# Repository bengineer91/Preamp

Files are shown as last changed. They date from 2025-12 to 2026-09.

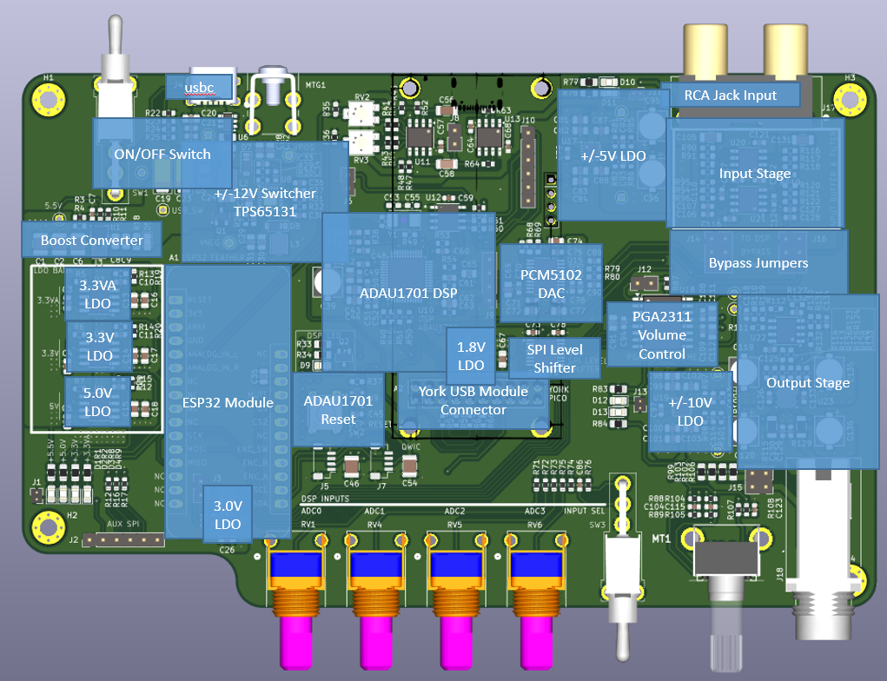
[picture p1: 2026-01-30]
layout/component_locations.PNG

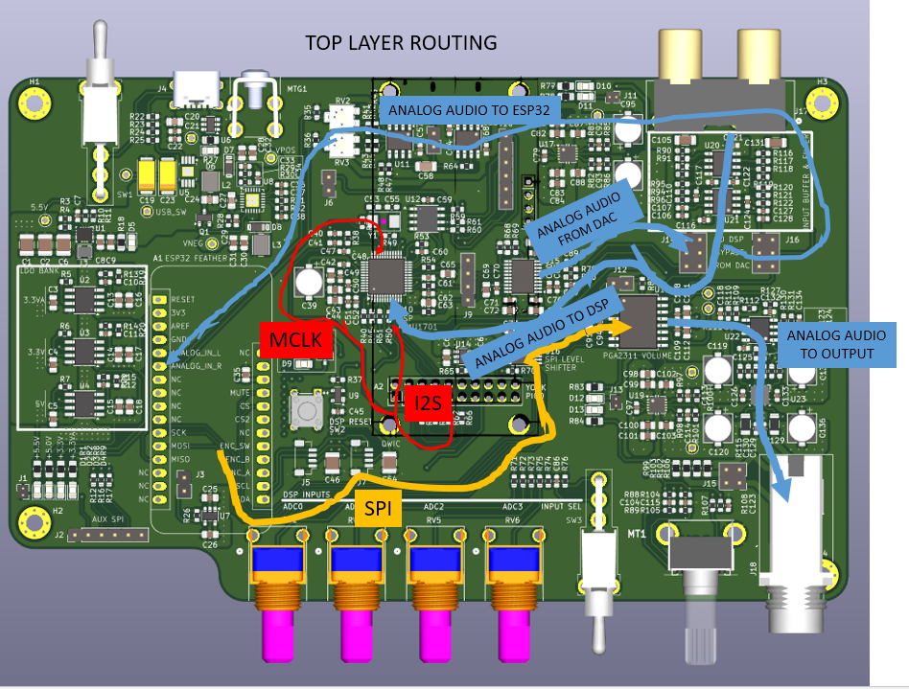
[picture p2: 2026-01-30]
layout/routing_overview.PNG

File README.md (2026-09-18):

# Preamp
** Note ** This got to the ready-to-buy-boards stage when I archived it for more interesting things.

Headphone amplifier with the following features:

- USBC Power Input
- 5V, 3.3V, 3.3VA, and 1.8V LDOs
- +/-12V split rail switching converter, feeding +/-10V and +/-5V LDOs
- ESP32 Module for control and driving a spectrum visualizer OLED display
- York Pico USB to I2S module
- ADAU1701 DSP
- PCM5102A Digital to Analog Converter
- PGA2311 digital volume controller

block_diagram
Capture

**To Do:** <br/>
[x] Update Block Diagram with power architecture changes<br/>

Layout:<br/>
[x] Verify component placement<br/>
[x] Routing!<br/>

Schematic:<br/>
[x] Clean up placement<br/>
[x] Part selection for capacitors, verify voltages on schematic<br/>
[x] Reduce footprint sizes where possible, mainly capacitors<br/>
[x] Pick proper connectors for the front panel stuff<br/>
[ ] Decide on header stack height for the York and ESP32<br/>

ESP32 Code<br/>
[x] Port over spectrum visualizer<br/>
[ ] PGA control<br/>

CAD<br/>
[x] Import board step file<br/>
[x] Figure out rear mounting<br/>
[ ] Layout front/rear panels <br/>

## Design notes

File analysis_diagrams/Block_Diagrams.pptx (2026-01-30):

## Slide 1

Power Converter Chain

USB-C Connector

USB Switch

5V -> 5.5V Boost Converter

5V -> +/-12V Conv

+/-10V LDO

+/-5V LDO

Toggle Switch

3.3VA LDO

3.3VDD LDO

1.8VDD LDO

5VDD LDO

3.0V LDO

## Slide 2

1x toggle switch

Bypass

Toggle Switch

RCA Jack Input

4x rotary potentiometers

PCM5102A DAC

OPAxxxx
Input buffer and DC block

OPAxxxx
Bessel Low Pass Filter

ADAU1701 DSP

PGA2311 Volume Control

Output Stage

I2C, I2S

York Audio Module

EEPROM

Headphone Jack

OLED Display

ESP32
ADC

OPAxxxx
Unity Gain Non Inverting Input Buffer

I2C

SPI

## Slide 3

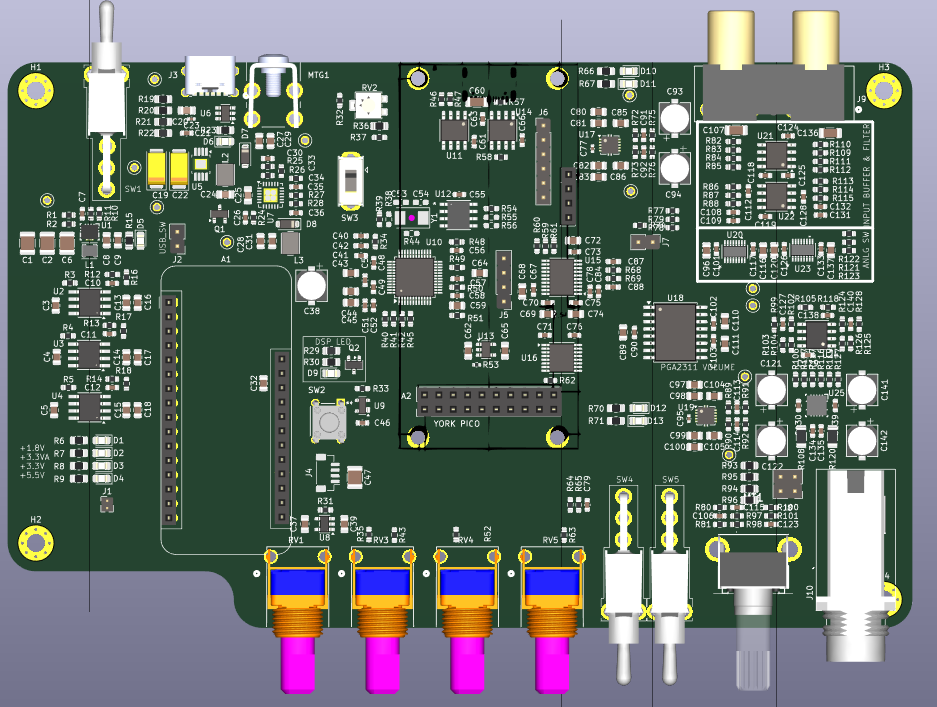
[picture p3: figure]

usbc

+/-5V LDO

RCA Jack Input

Input Stage

Analog Switches

Output Stage

ON/OFF Switch

+/-12V Switcher
TPS65131

ESP32 Module

Boost Converter

ADAU1701 DSP

York USB Module Connector

5.0V LDO

PCM5102 DAC

SPI Level Shifter

3.3VA LDO

1.8V LDO

PGA2311 Volume Control

+/-10V LDO

3.3V LDO

ADAU1701 Reset

3.0V LDO

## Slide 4

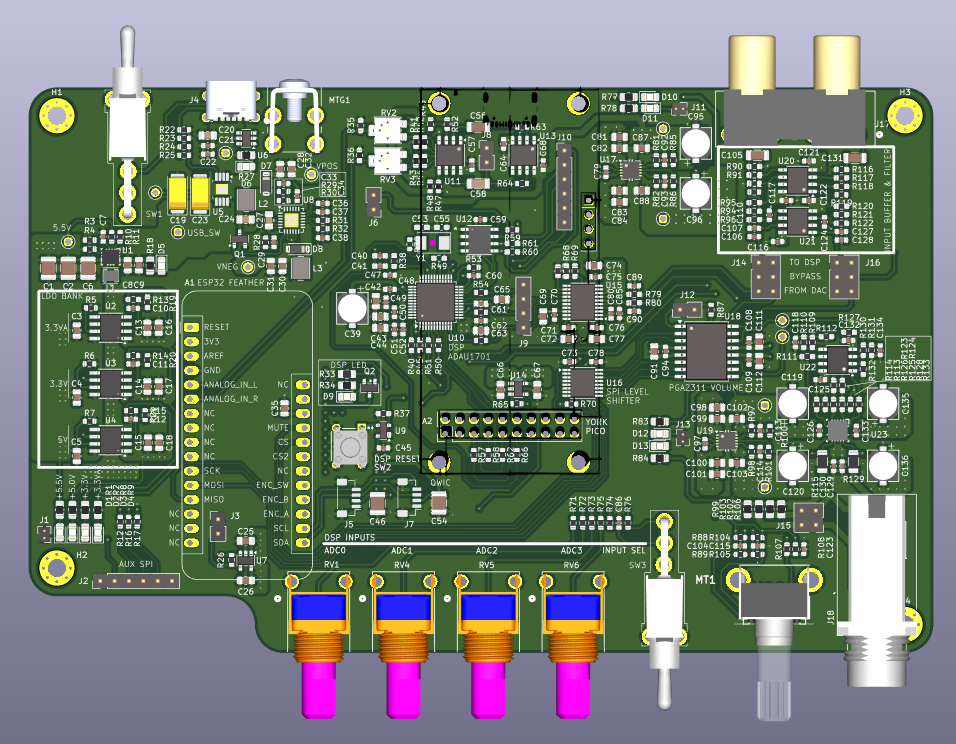
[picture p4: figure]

usbc

+/-5V LDO

RCA Jack Input

Input Stage

Bypass Jumpers

Output Stage

ON/OFF Switch

+/-12V Switcher
TPS65131

ESP32 Module

Boost Converter

ADAU1701 DSP

York USB Module Connector

3.3VA LDO

PCM5102 DAC

SPI Level Shifter

3.3V LDO

1.8V LDO

PGA2311 Volume Control

+/-10V LDO

5.0V LDO

ADAU1701 Reset

3.0V LDO

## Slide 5

TOP LAYER ROUTING

ANALOG AUDIO TO ESP32

ANALOG AUDIO
FROM DAC

ANALOG AUDIO TO DSP

MCLK

I2S

ANALOG AUDIO
TO OUTPUT

SPI

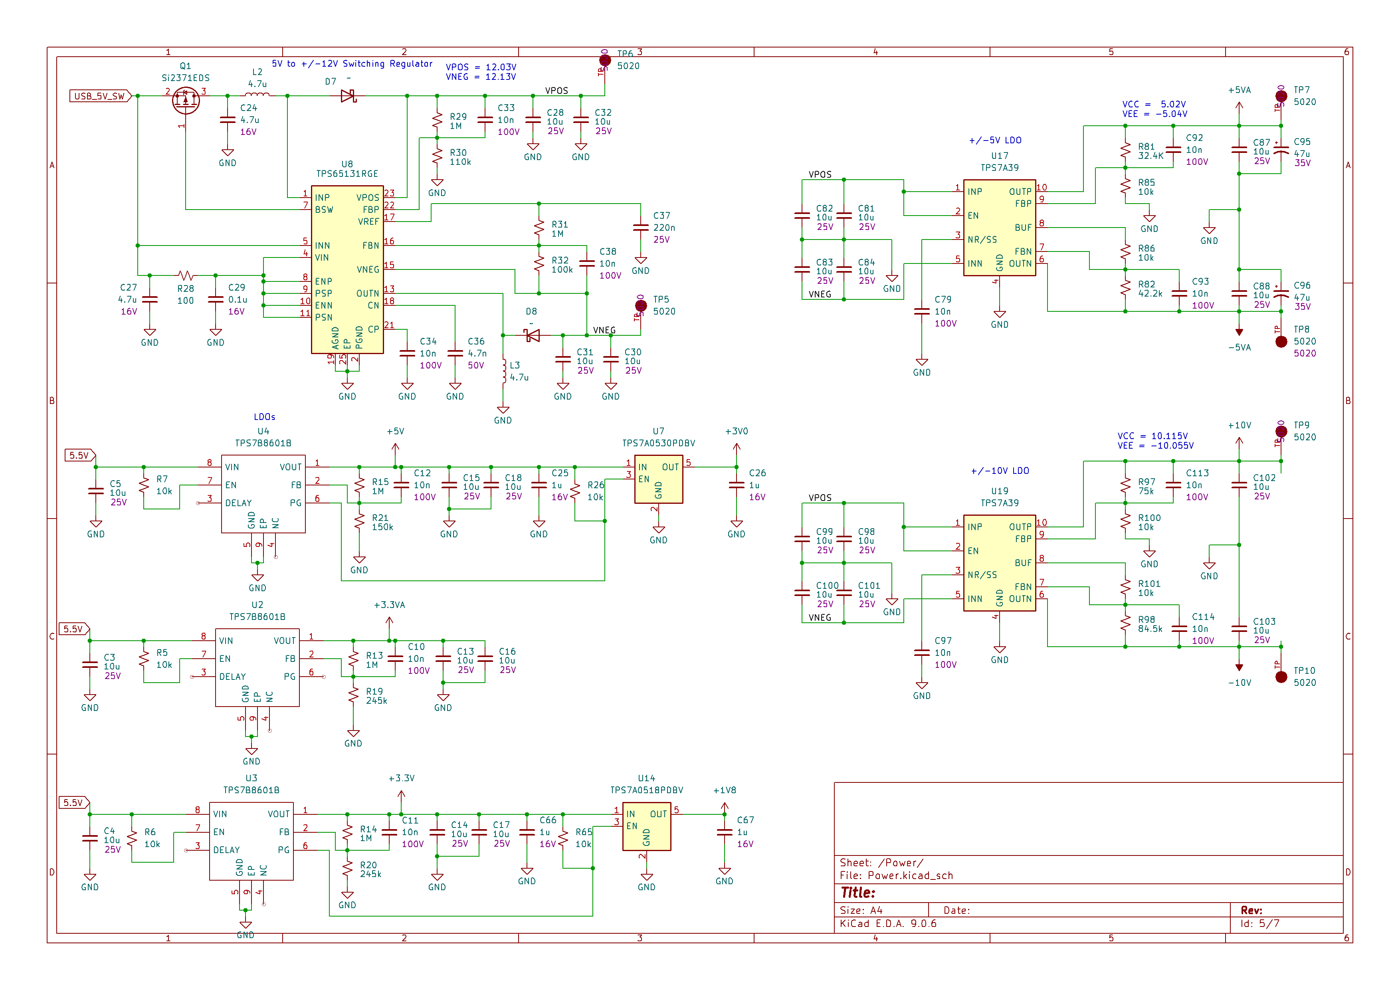
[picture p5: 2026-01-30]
schematic/sheet5.png

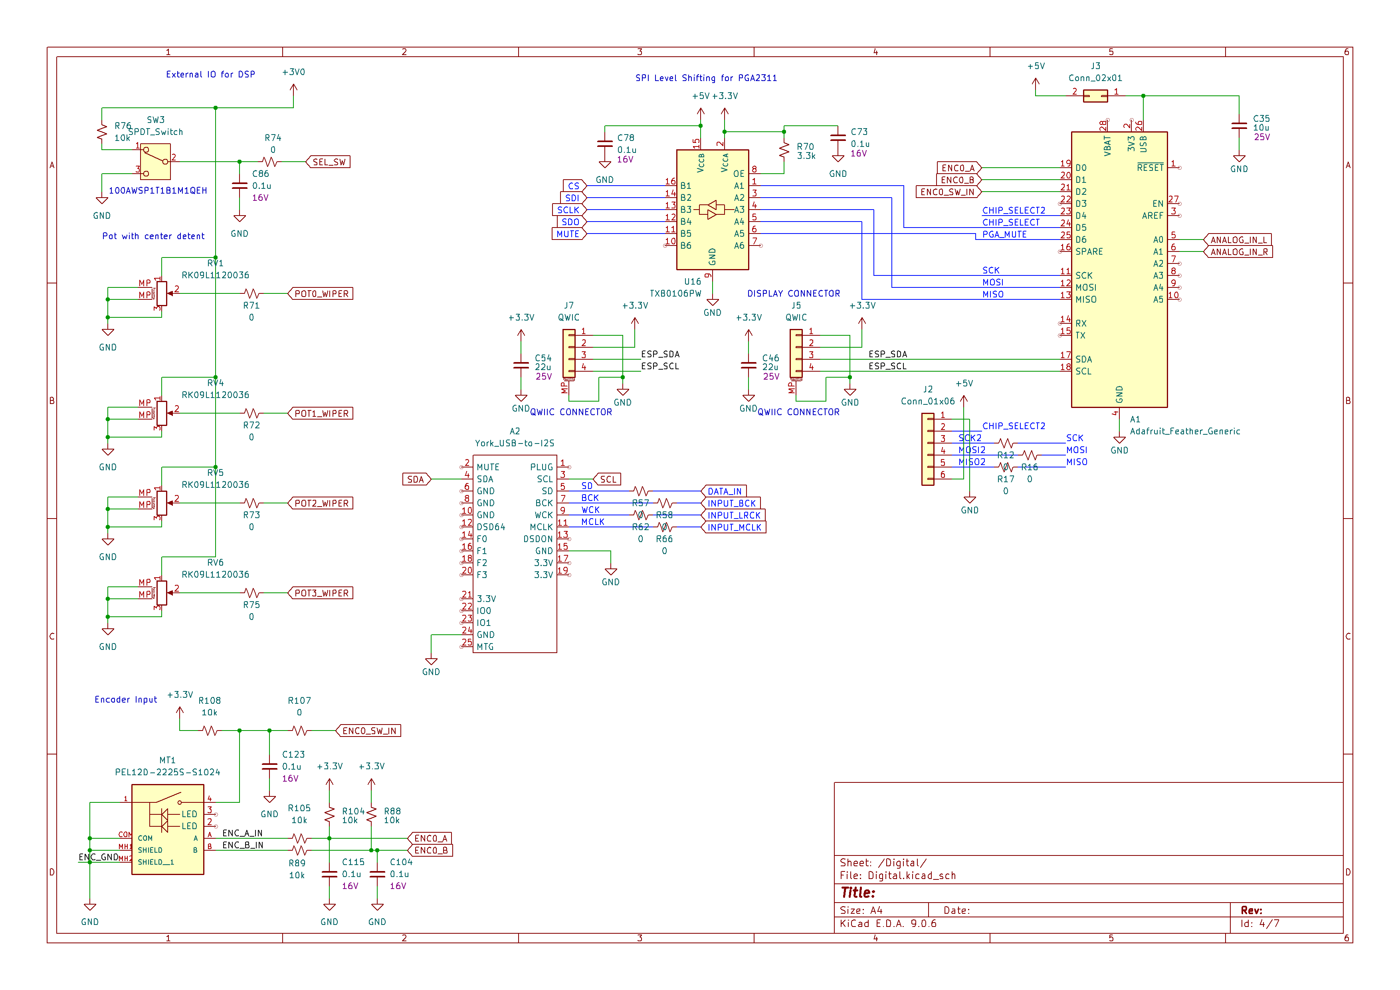
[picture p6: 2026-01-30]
schematic/sheet4.png

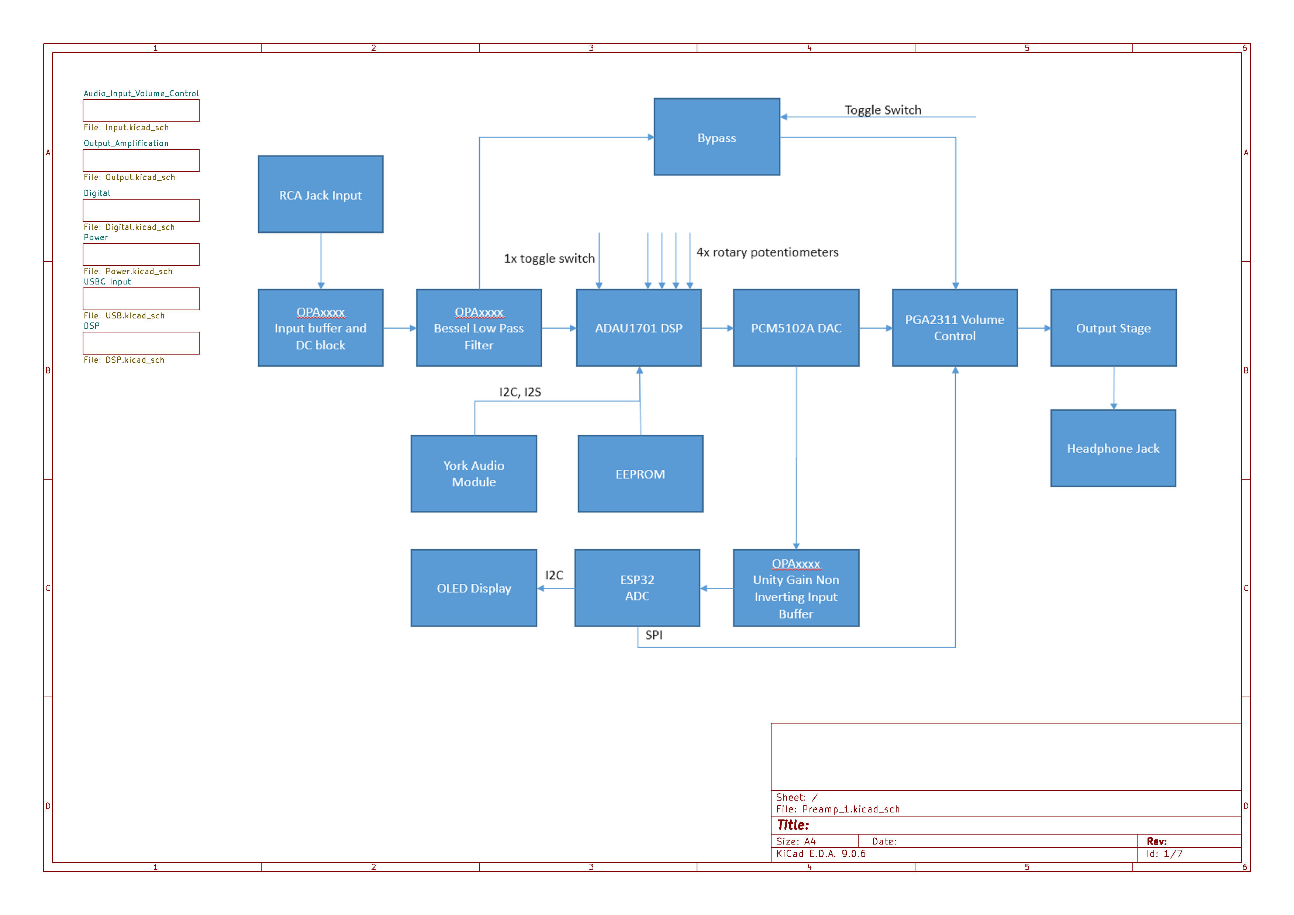
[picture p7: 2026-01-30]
schematic/sheet1.png

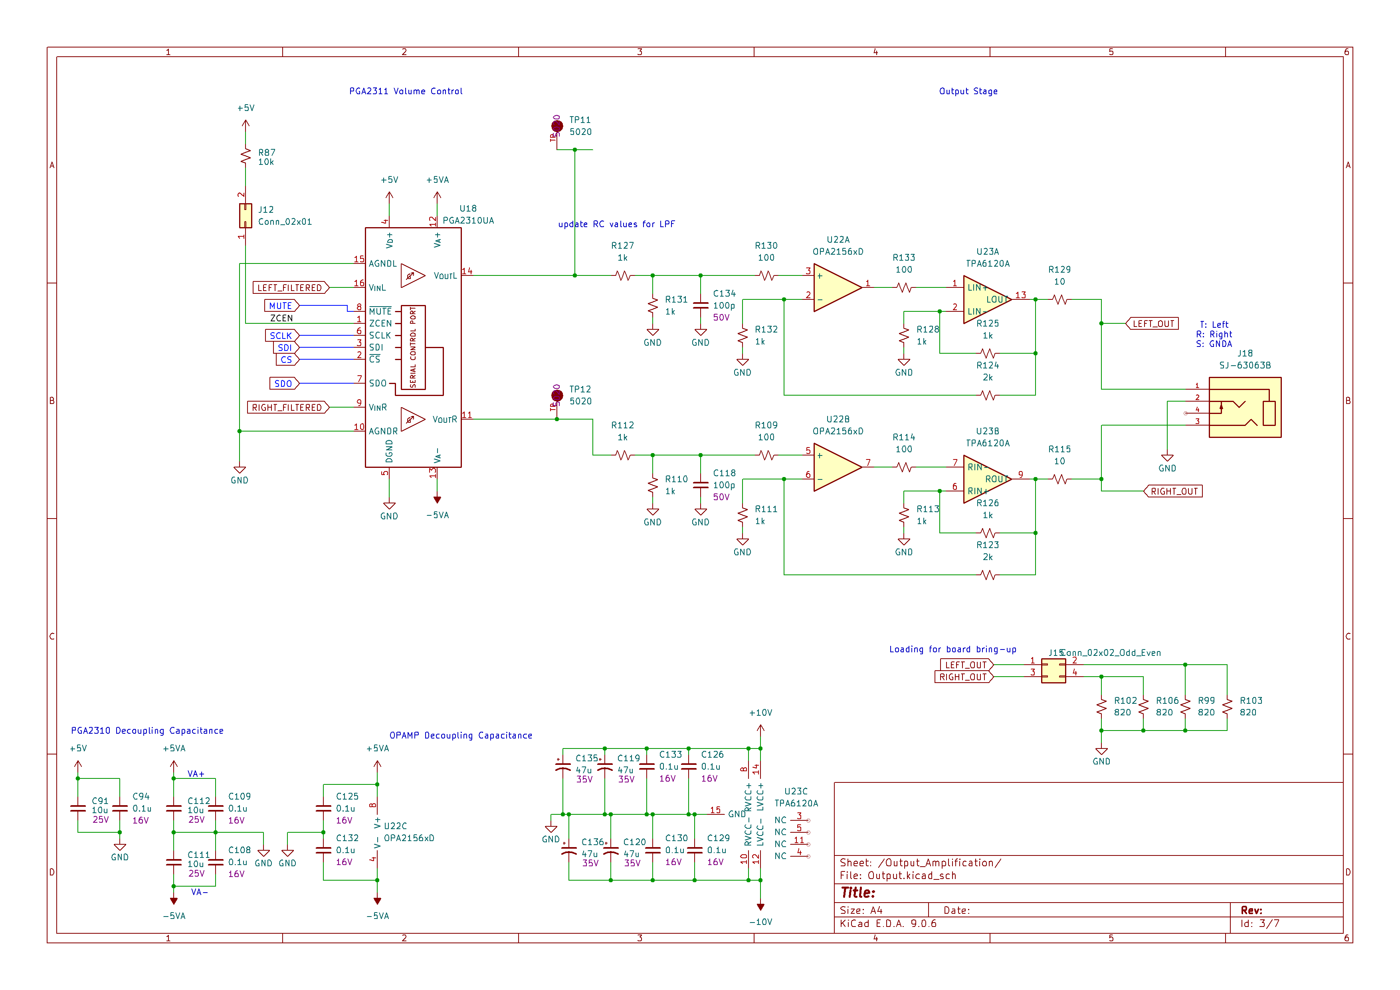
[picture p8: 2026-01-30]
schematic/sheet3.png

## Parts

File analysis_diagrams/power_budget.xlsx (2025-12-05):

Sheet: Power Budget (2)
 |  |  | Power Budget |  |  | 2949.1 | mW
 | Refdes | Device | Voltage Rail | Voltage | Current (mA) | Power (mW)
Input Buffer | U21 | Opamp (signal) | VCC (5V) | 5 | 10 | 50
Input Buffer | U21 | Opamp (signal) | VEE (-5V) | 5 | 10 | 50
Input Filter | U22 | Opamp (signal) | VCC (5V) | 5 | 10 | 50
Input Filter | U22 | Opamp (signal) | VEE (-5V) | 5 | 10 | 50
Input Buffer - EPS32 | U14 | Opamp (signal) | VCC (5V) | 5 | 10 | 50
Input Buffer - EPS32 | U14 | Opamp (signal) | VEE (-5V) | 5 | 10 | 50
ESP32 Summer | U11 | Opamp (amp) | VCC (5V) | 5 | 10 | 50
none | U11 | Opamp (amp) | VEE (-5V) |  |  | 0
Output Stage | U24 | Opamp (amp) | VCC (5V) | 5 | 10 | 50
Output Stage | U24 | Opamp (amp) | VEE (-5V) | 5 | 10 | 50
Output Stage | U25 | Opamp (amp) | VCC (10V) | 10 | 50 | 500
Output Stage | U25 | Opamp (amp) | VEE (-10V) | 10 | 50 | 500
Switches | U20 | Analog Switch | VCC (5V) | 5 | 1 | 5
 | U20 | Analog Switch | VEE (-5V) | 5 | 1 | 5
 | U23 | Analog Switch | VCC (5V) | 5 | 1 | 5
 | U23 | Analog Switch | VEE (-5V) | 5 | 1 | 5
 | U18 | PGA2311 | 5VDD | 5 | 1 | 5
 | U18 | PGA2311 | VCC (5V) | 5 | 8 | 40
 | U18 | PGA2311 | VEE (-5V) | 5 | 10 | 50
 | A1 | ESP32 | 5VDD | 5 | 80 | 400
LEVEL SHIFTER | U16 | TXB106PW | 3.3VDD | 3.3 | 5 | 16.5
 |  |  | 5VDD | 5 | 5 | 25
 |  | Display | 3.3VDD | 3.3 | 100 | 330
 | U15 | PCM5102A | 3.3VA | 3.3 | 44 | 145.2 | 3.3VA (AVDD, CPVDD)
 | U15 | PCM5102A | 3.3VDD | 3.3 | 9 | 29.7 | 3.3VDD (VDD)
 | U15 | PCM5102A | 1.8V | 1.8 | 9 | 16.2 | LDOO
 | U10 | ADAU1701 | 3.3VA | 3.3 | 42.5 | 140.25 | AVDD | analog
 | U10 | ADAU1701 | 1.8V | 1.8 | 60 | 108 | DVDD | digital
 | U10 | ADAU1701 | 3.3VA | 3.3 | 42.5 | 140.25 | PVDD | PLL
 | U10 | ADAU1701 | 3.3VDD | 3.3 | 10 | 33 | IOVDD | IO
 |  | Regulator | Voltage Rail | Input Voltage | Output Voltage | Current Limit | Current (mA) | Power Diss (mW) | Theta_JA (C/W) | delta_C | Theta_JB (C/W)
 | U17 | TPS7A39 | VCC (5V) | 12 | 5 | 150 | 60 | 420 | 44.4 | 18.648
 | U17 | TPS7A39 | VEE (-5V) | 12 | 5 | 150 | 52 | 364 | 44.4 | 16.1616
 | U19 | TPS7A39 | VCC (10V) | 12 | 10 | 150 | 50 | 100 | 45.4 | 4.54
 | U19 | TPS7A39 | VEE (-10V) | 12 | 10 | 150 | 50 | 100 | 46.4 | 4.64
 |  |  |  | 5 | 5 | 500 | 69 | 0 | 29.7 | 0
 | U3 | TPS7B8601 | 5VDD | 5.5 | 5 | 500 | 96 | 48 | 41 | 1.968
 | U4 | TPS7B8601 | 3.3VDD | 5 | 3.3 | 500 | 193 | 328.1 | 41 | 13.4521
 | U2 | TPS7B8601 | 3.3VA | 5 | 3.3 | 500 | 129 | 219.3 | 41 | 8.9913
 | U13 | TPS7A05 | 1.8V | 3.3 | 1.8 | 200 | 69 | 103.5 | 185.6 | 19.2096 | 54.5 | 5.64075
 | U8 | TPS7A05 | 3.0v | 5 | 3 | 200 | 10 | 20
 |  |  | Regulator | Current
 |  | P5.5V | Unreg 5V | 1 | 392 | 5 | 3528 |  | 5V | RKZE-0505S
 |  |  | 3.3VA | 129 |  | 425.7
 |  |  | 3.3VDD | 193 |  | 636.9
 |  |  | 1.8V | 69 |  | 124.2
 | U17 | P_12V | VCC (5V) | 60 |  | 720
 | U19 |  | VCC (10V) | 50 |  | 600
 | U17 | N_12V | VEE (-5V) | 52 | 102
 | U19 |  | VEE (-10V) | 50

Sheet: DSP Pinout and Config
Multipurpose | Serial Data | Analog | Use
MP0 | SDATA_IN0 / tdm_IN
MP1 | SDATA_IN1 |  | DATA_IN
MP2 | SDATA_IN2 | ADC1 | POT1
MP3 | SDATA_IN3 | ADC2 | POT2
MP4 | INPUT_LRCLK |  | INPUT_LRCK
MP5 | INPUT_BCLK |  | INPUT_BCK
MP6 | SDATA_OUT0 / TDM_OUT
MP7 | SDATA_OUT1 |  | DATA_OUT
MP8 | SDATA_OUT2 | ADC3 | POT3
MP9 | SDATA_OUT3 | ADC0 | POT0 | Pushbutton
MP10 | OUTPUT_LRCLK |  | OUTPUT_LRCK
MP11 | OUTPUT_BCLK |  | OUTPUT_BCK

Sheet: Setpoint Calcs
5V +/- LDO
TPS7A39 |  |  | V_NRSS | 1.19 | V
VOUTP | 10V |  | V_NRSS * (1+R1P/R2P) |  |  | 5.0456
VOUTN | N_10V |  | V_NRSS*(-R1N/R2N) |  |  | -5.0218
 |  |  | R1P | 32400 | ohm
 |  |  | R2P | 10000 | ohm
 |  |  | R1N | 42200 | ohm
 |  |  | R2N | 10000 | ohm
10V +/- LDO
TPS7A39 |  |  | V_NRSS | 1.19 | V
VOUTP | 10V |  | V_NRSS * (1+R1P/R2P) |  |  | 10.115
VOUTN | N_10V |  | V_NRSS*(-R1N/R2N) |  |  | -10.0555
 |  |  | R1P | 75000 | ohm
 |  |  | R2P | 10000 | ohm
 |  |  | R1N | 84500 | ohm
 |  |  | R2N | 10000 | ohm
Split Rail Switcher
TPS65131RGE |  |  | V_REF | 1.213 | V
VOUTP | 12V |  | R1/R2*V_REF+1 |  |  | 12.02727273
VOUT_N | N_12V |  | R3/-R4*V_REF |  |  | -12.13
 |  |  | R1 | 1000000 | ohm
 |  |  | R2 | 110000 | ohm
 |  |  | R3 | 1000000 | ohm
 |  |  | R4 | 100000 | ohm
TPS7B8601
VOUT | 5 |  | V_REF | 0.65 | V
 |  |  | V_REF*(1+R1/R2) |  |  | 4.983333333
 |  |  | IADJ | 1e-08 | A | 1e-08
 |  | Upper | R1 | 1000000 | 1M
 |  | Lower | R2 | 150000 | 150k | CFF | 10 | nF
 |  |  | r_sum | 1150000 | 5000000
TPS7B8601
VOUT | 3.3 |  | V_REF | 0.65 | V
 |  |  | V_REF*(1+R1/R2) |  |  | 3.303061224
 |  |  | IADJ | 1e-08 | A | 1e-08
 |  | Upper | R1 | 1000000 | 1M
 |  | Lower | R2 | 245000 | 245k | CFF | 10 | nF
 |  |  | r_sum | 1245000 | 3300000
TPS7B8601
VOUT | 1.8 |  | V_REF | 0.65 | V
 |  |  | V_REF*(1+R1/R2) |  |  | 1.810714286
 |  |  | IADJ | 1e-08 | A | 1e-08
 |  | Upper | R1 | 1000000 | 1M
 |  | Lower | R2 | 560000 | 56k | CFF | 10 | nF
 |  |  | r_sum | 1560000 | 1800000

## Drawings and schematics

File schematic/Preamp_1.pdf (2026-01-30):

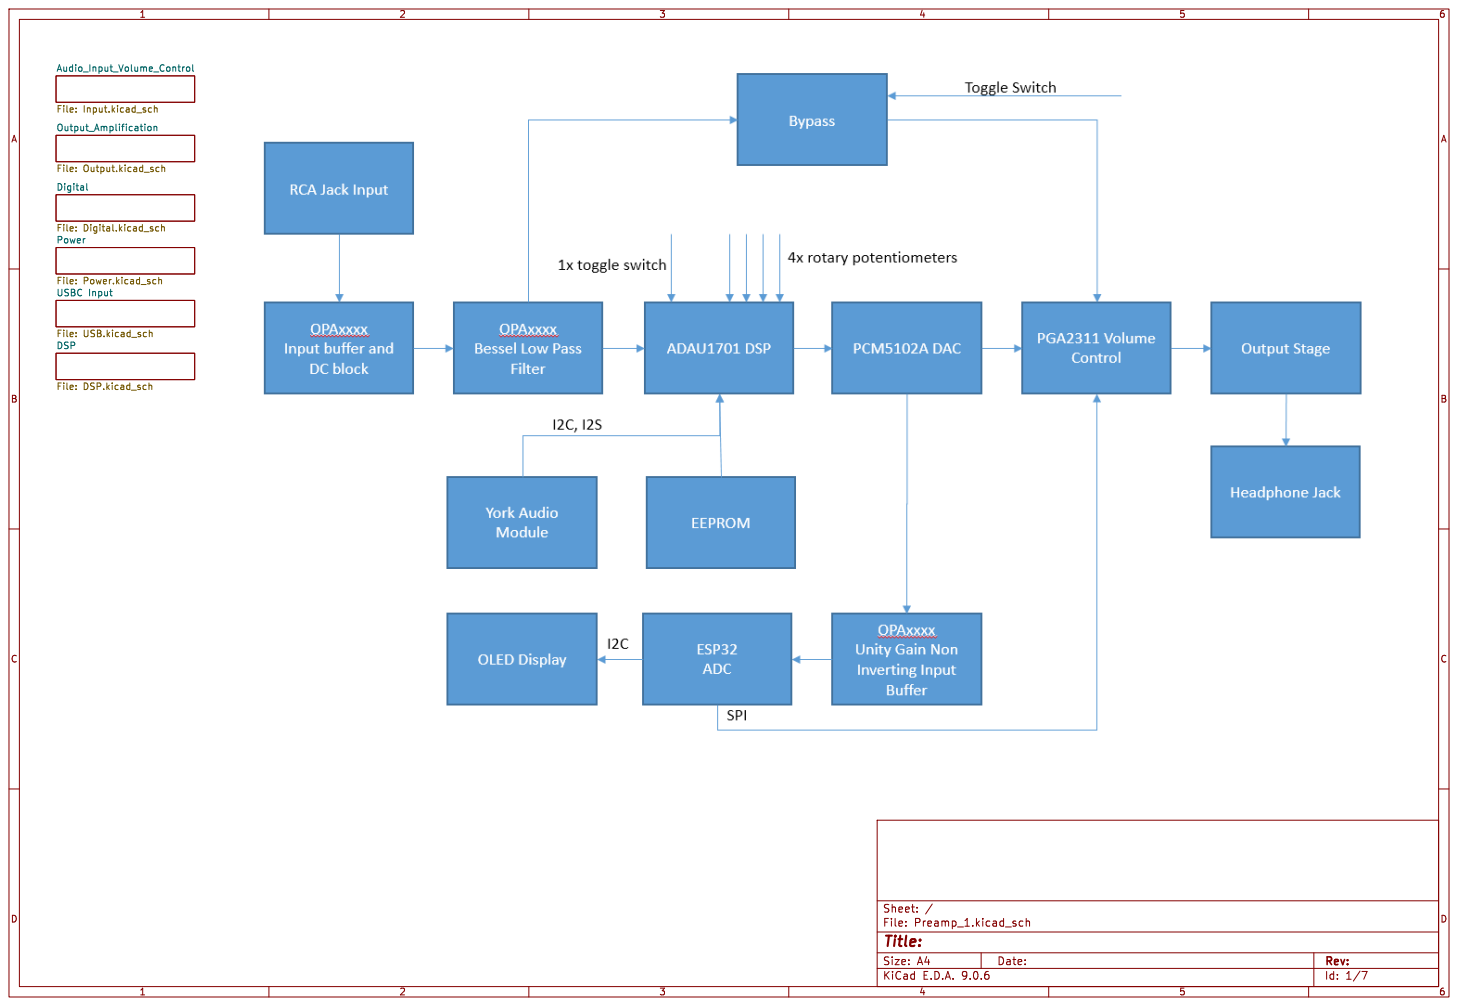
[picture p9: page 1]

File: DSP.kicad_sch Audio_Input_Volume_Control File: Input.kicad_sch Power File: Power.kicad_sch Output_Amplification File: Output.kicad_sch USBC Input File: USB.kicad_sch

Digital File: Digital.kicad_sch DSP

Id: 1/7 Title: File: Preamp_1.kicad_sch Sheet: /

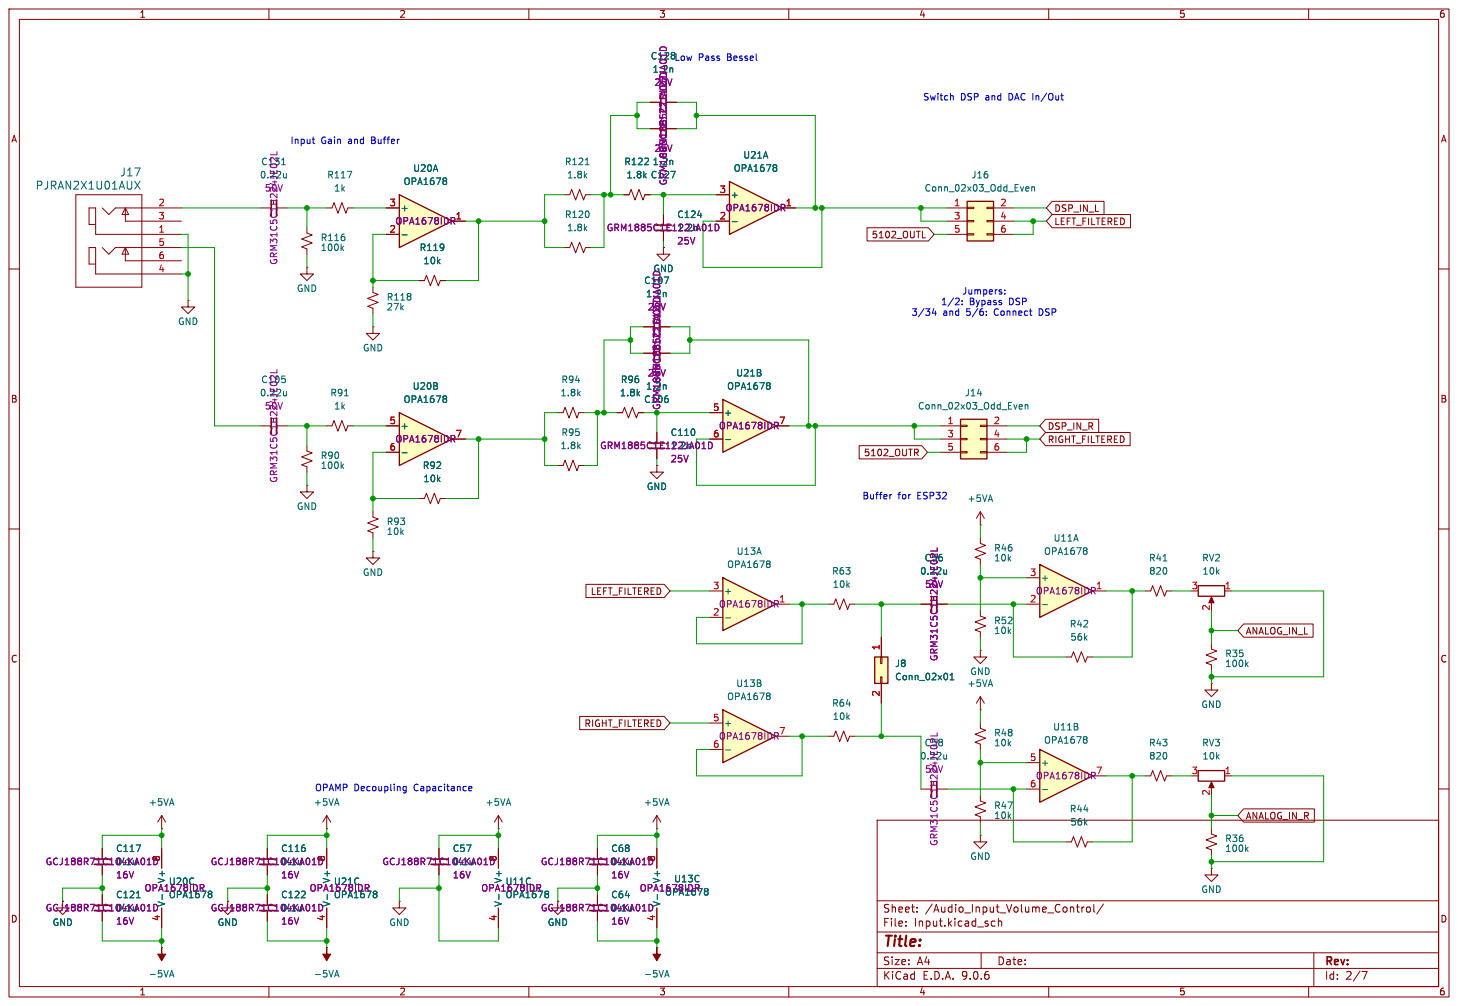
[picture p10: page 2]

Id: 2/7 Title: File: Input.kicad_sch Sheet: /Audio_Input_Volume_Control/R42

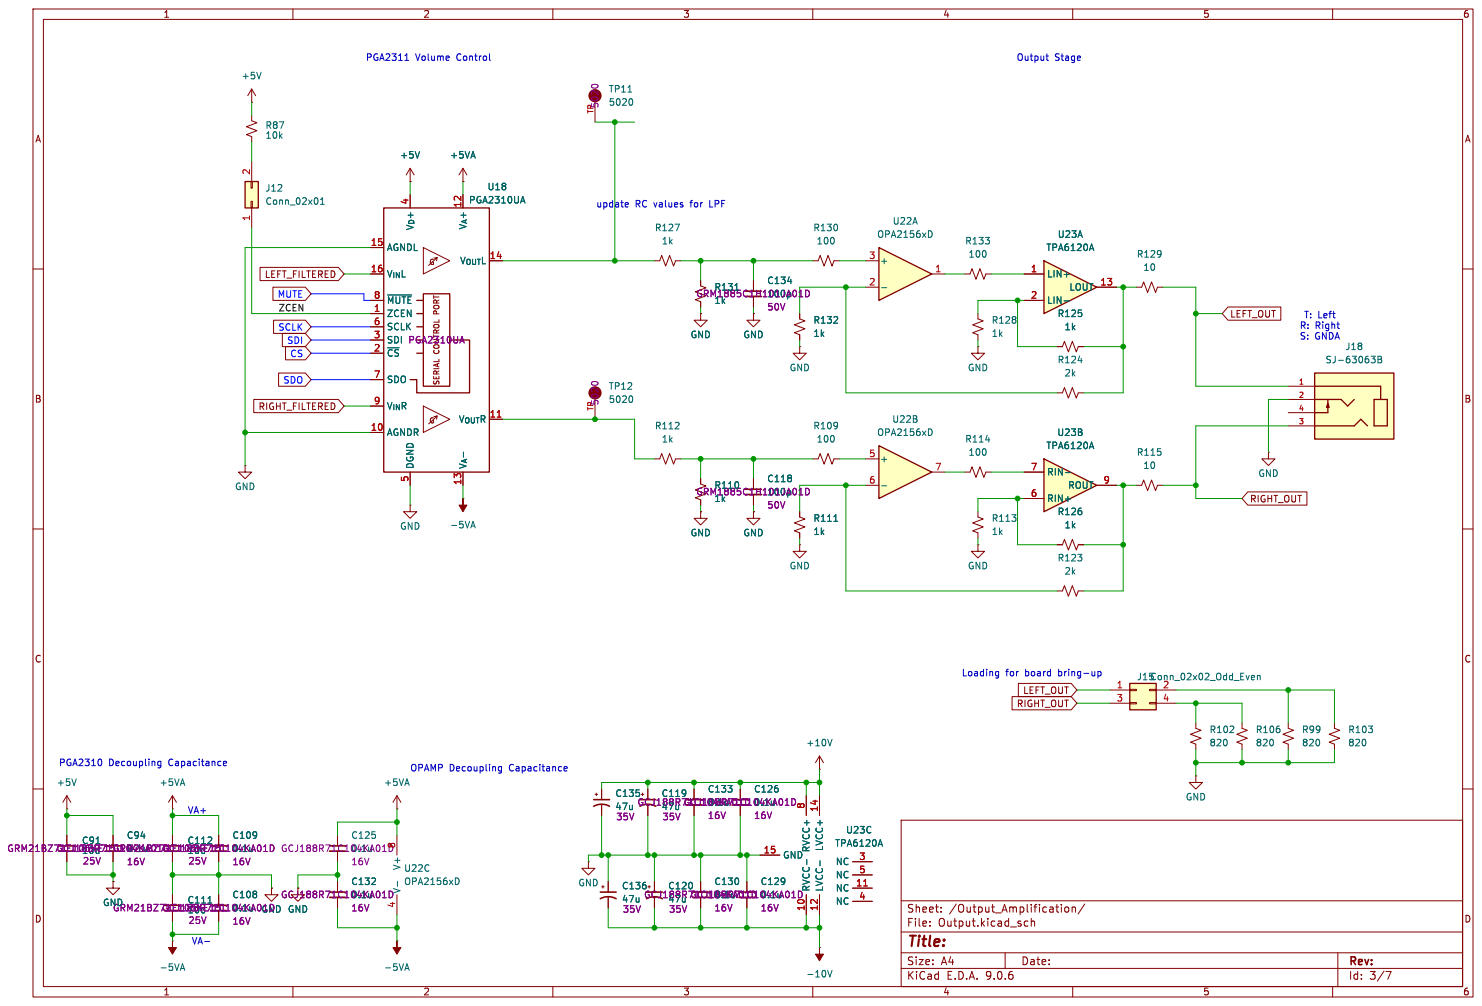
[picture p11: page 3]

Id: 3/7 Title: File: Output.kicad_sch Sheet: /Output_Amplification/ R113

Loading for board bring-up VA-

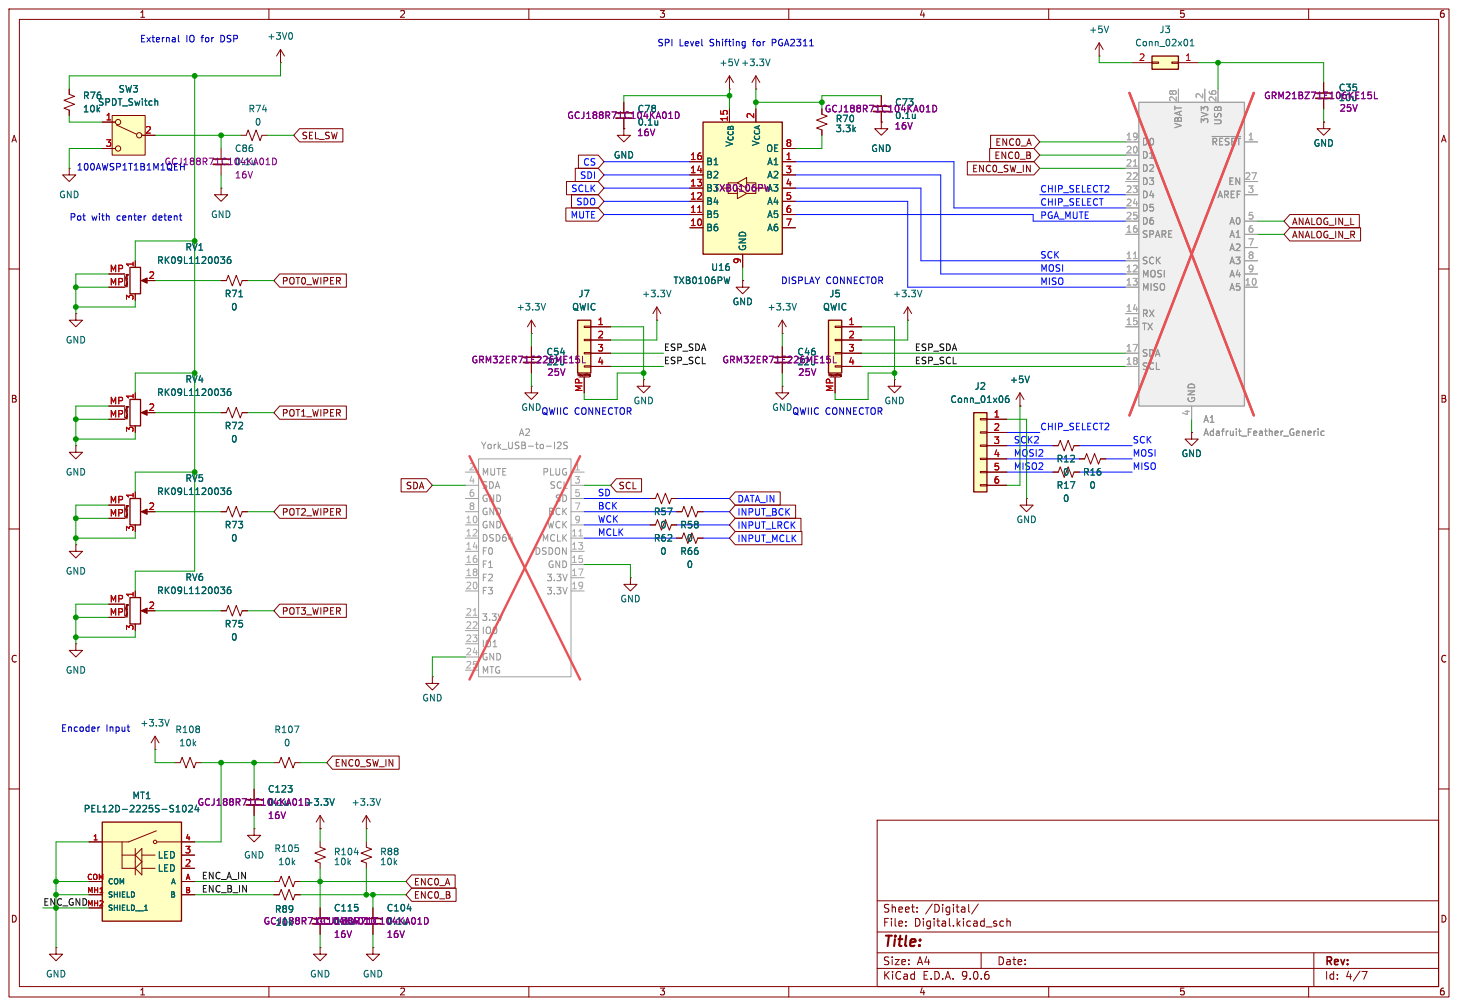
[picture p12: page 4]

Pot with center detent 100AWSP1T1B1M1QEH

+5V GND Mounting MP MP

0 MUTE 2 SDA 4 GND 6 GND 8 GND 10 DSD64 12 F0 14 F1 16 F2 18 F3 20

Id: 4/7 Title: File: Digital.kicad_sch Sheet: /Digital/ C123

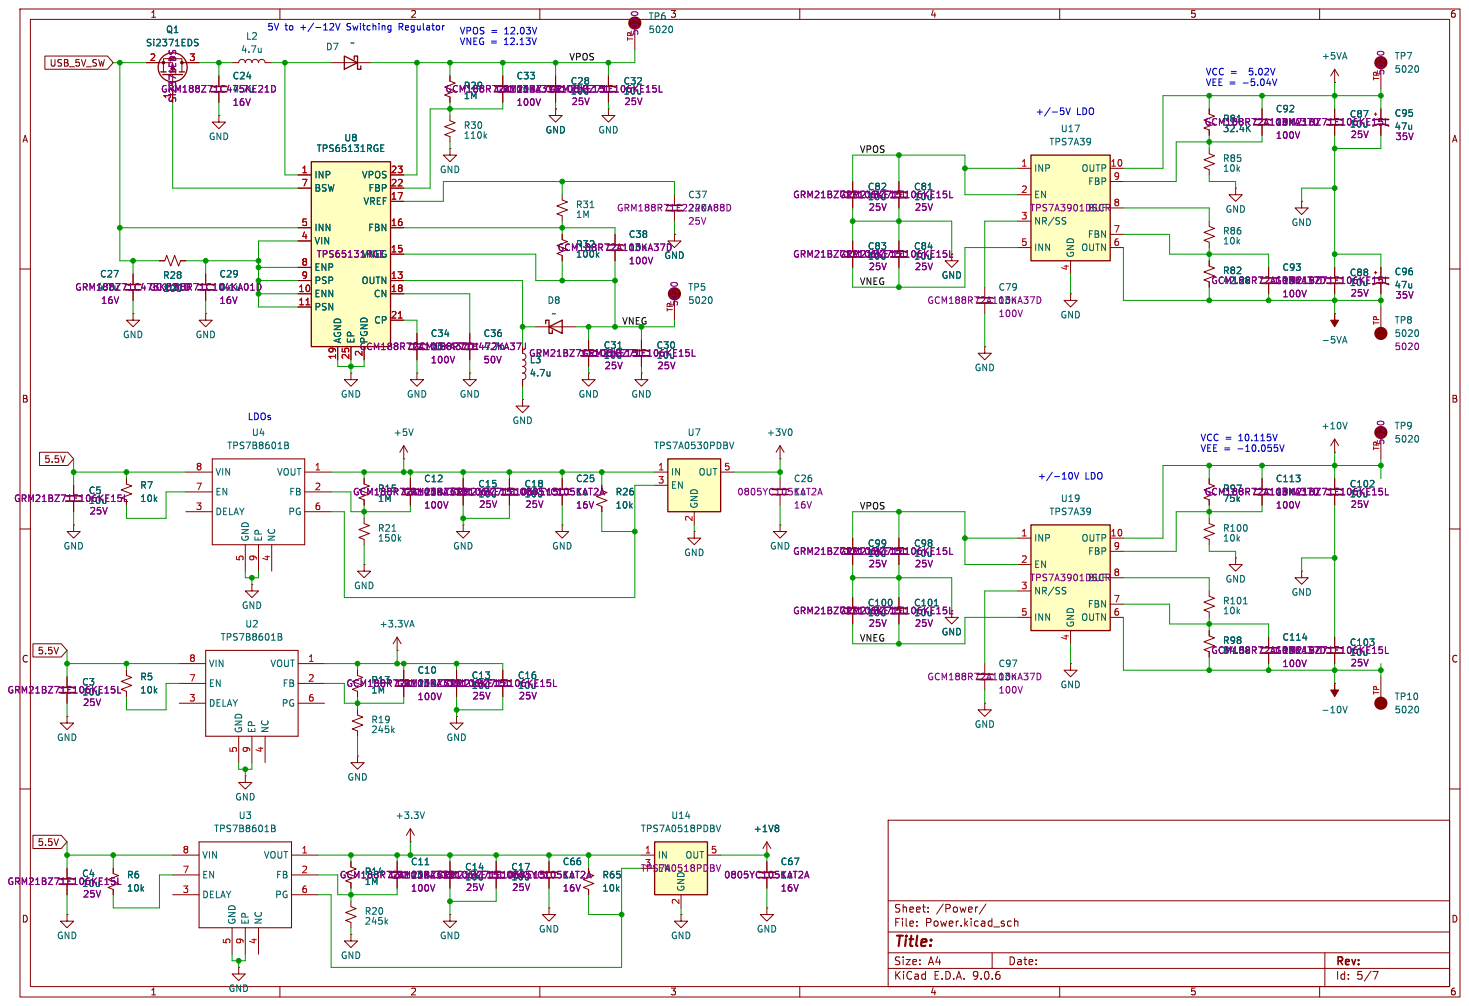
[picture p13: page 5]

4 OUTP 10 FBP 9 BUF 8 FBN 7 OUTN 6 U17 TPS7A39 TPS7A3901DSCR

2 VPOS 23 FBP 22 VREF 17 FBN 16 VNEG 15 OUTN 13 CN 18 CP 21 U8 TPS65131RGE

2 VPOS 23 FBP 22 VREF 17 FBN 16 VNEG 15 OUTN 13 CN 18 CP 21 R15

4 OUTP 10 FBP 9 BUF 8 FBN 7 OUTN 6 U19 TPS7A39 TPS7A3901DSCR GND GND

INP 1 EN 2 NR/SS 3

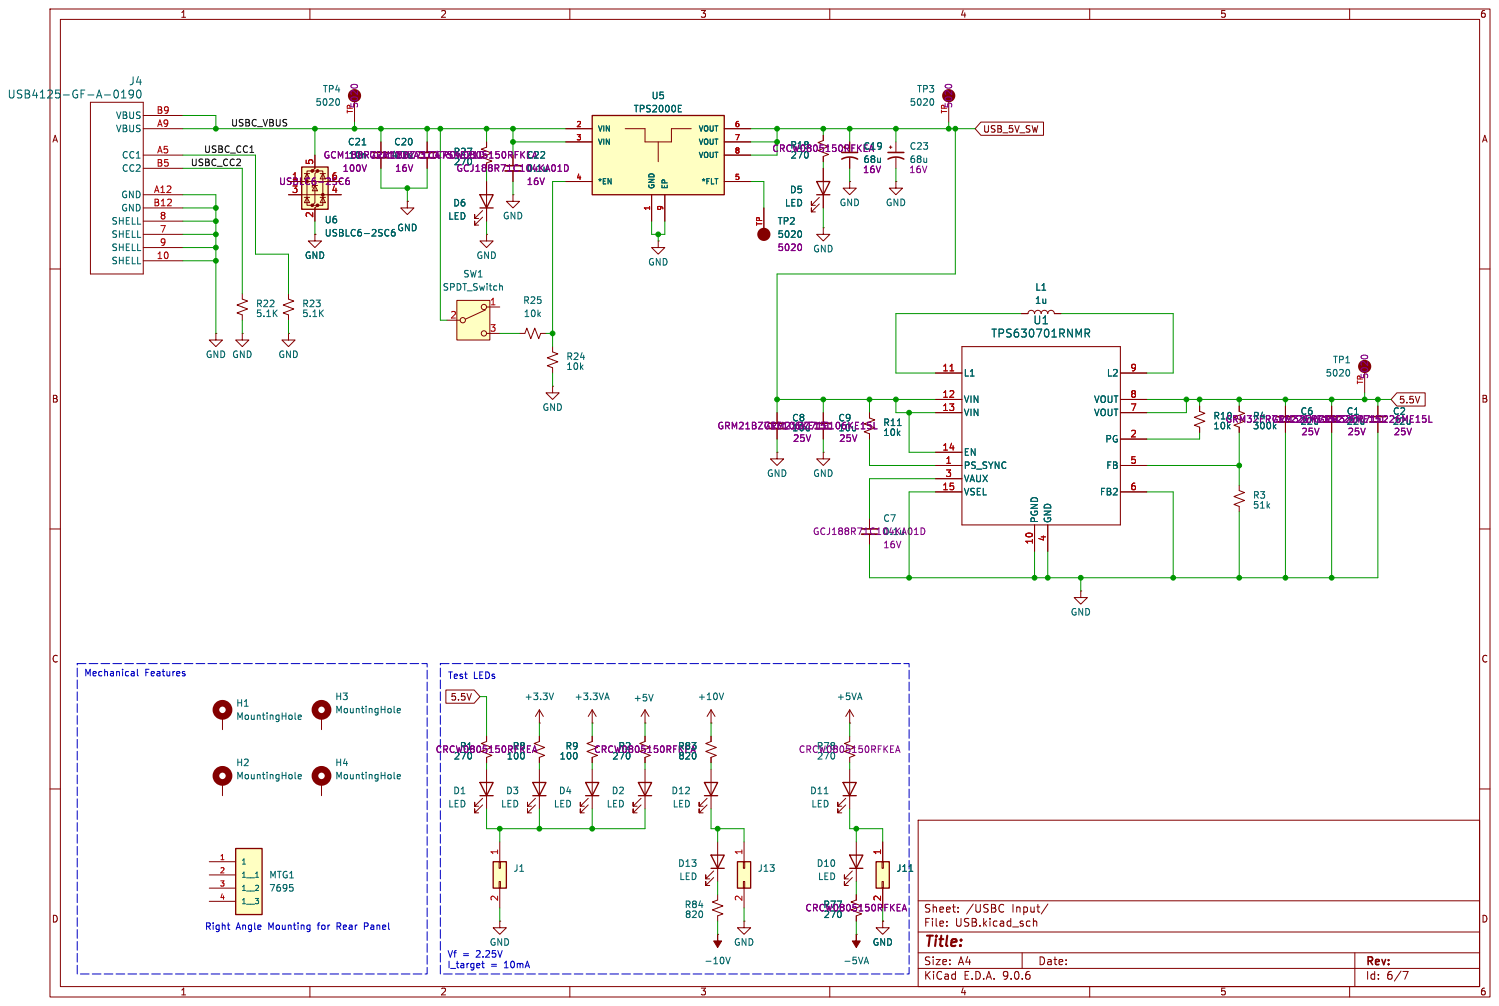
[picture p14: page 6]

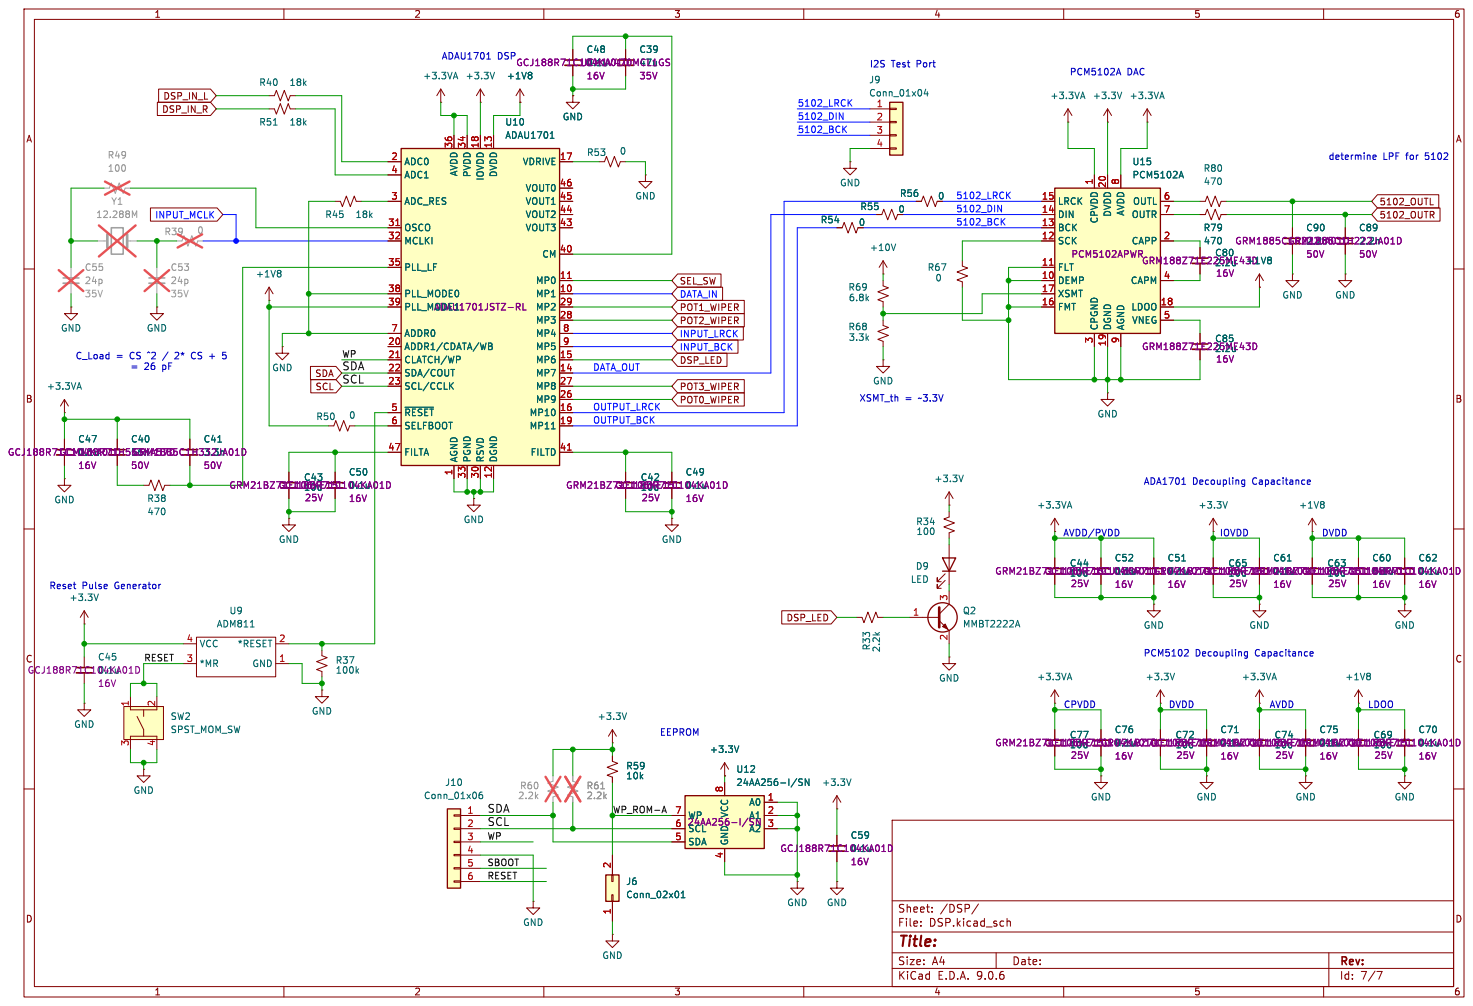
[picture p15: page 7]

1 PVDD 34 PGND 33 IOVDD 18 RSVD 30 DVDD 13 DGND 12 VDRIVE 17 VOUT0 46 VOUT1 45 VOUT2 44 VOUT3 43 CM 40 MP0 11 MP1 10 MP2 29 MP3 28 MP4 8 MP5 9 MP6 15 MP7 14 MP8 27 MP9 26 MP10 16 MP11 19 FILTD 41 U10 ADAU1701 ADAU1701JSTZ-RL R80

1 PVDD 34 PGND 33 IOVDD 18 RSVD 30 DVDD 13 DGND 12 VDRIVE 17 VOUT0 46 VOUT1 45 VOUT2 44 VOUT3 43 CM 40 MP0 11 MP1 10 MP2 29 MP3 28 MP4 8 MP5 9 MP6 15 MP7 14 MP8 27 MP9 26 MP10 16 MP11 19 FILTD 41GND

9 OUTL 6 OUTR 7 CAPP 2 CAPM 4

Id: 7/7 Title: File: DSP.kicad_sch Sheet: /DSP/
